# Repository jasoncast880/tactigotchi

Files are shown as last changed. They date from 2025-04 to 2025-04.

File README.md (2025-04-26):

🚀 Project Title

A handheld system based on the Raspberry Pi Pico W
📦 Overview

This project features:

    Custom hardware using RP2040

    Firmware written in C/C++ using GCC & Pico SDK

    Support for SPI LCD Display & SD Card, I2C Buttons, Wi-Fi, BLE, DMA Data Transfer (PIO is WIP)

🔧 Hardware
Microcontroller

    Board: [e.g., Raspberry Pi Pico / STM32F401 / ESP32]

    Processor: [e.g., ARM Cortex-M0+ @ 133MHz]

Schematic & PCB <br>
MCU Schematic:<br>
<br>
PSU:<br>
<br>
LCD/SDC THT Module:<br>
<br>
Speaker && IR Emitter Modules:<br>
<br>

    [Link to schematic or image]

    [Link to PCB files or KiCad/Altium project]

🧠 Firmware
Features

[Feature 1 – e.g., Sensor reading with ADC]

[Feature 2 – e.g., Wi-Fi transmission]

    [Planned Feature – e.g., OTA firmware update]

Toolchain

    Language: C/C++

    Build System: CMake

    RTOS: FreeRTOS

    SDK: Raspberry Pi Pico SDK v1.5.1 (update)

Directory Structure (update...)

project/
├── hardware/         # Schematics, PCB design files
├── pockpet/
└── README.md

🚀 Getting Started
Requirements

    Compiler/toolchain: arm-none-eabi-gcc

    A 'Tactigotchi' official hardware kit!

Building the Firmware

git clone https://github.com/yourusername/project.git
cd project
mkdir build && cd build
cmake ..
make

Flashing to Device

# Example for Raspberry Pi Pico (drag-and-drop)
cp firmware.uf2 /media/PI-PICO/

Or, using OpenOCD / pyOCD:

openocd -f interface/cmsis-dap.cfg -f target/rp2040.cfg

📈 Performance & Testing

    Power consumption: [value]

    Real-time responsiveness: [value / approach used]

    Debugging methods: [e.g., UART, SWD, printf-style logging]

🗂️ Documentation

    [Link to datasheets, application notes, or online documentation]

    [Optional: Link to a GitHub Wiki or Doxygen-generated docs]

🧪 Development Notes

    Known Issues: [List any bugs or limitations]

    Future Work: [Planned improvements or extensions]

    Contributions: [Mention if pull requests/issues are welcome]

📜 License

[MIT / GPL / Apache 2.0 / etc.]
🙌 Acknowledgments

    [Any libraries or codebases used]

    [Contributors, inspirations, mentors]

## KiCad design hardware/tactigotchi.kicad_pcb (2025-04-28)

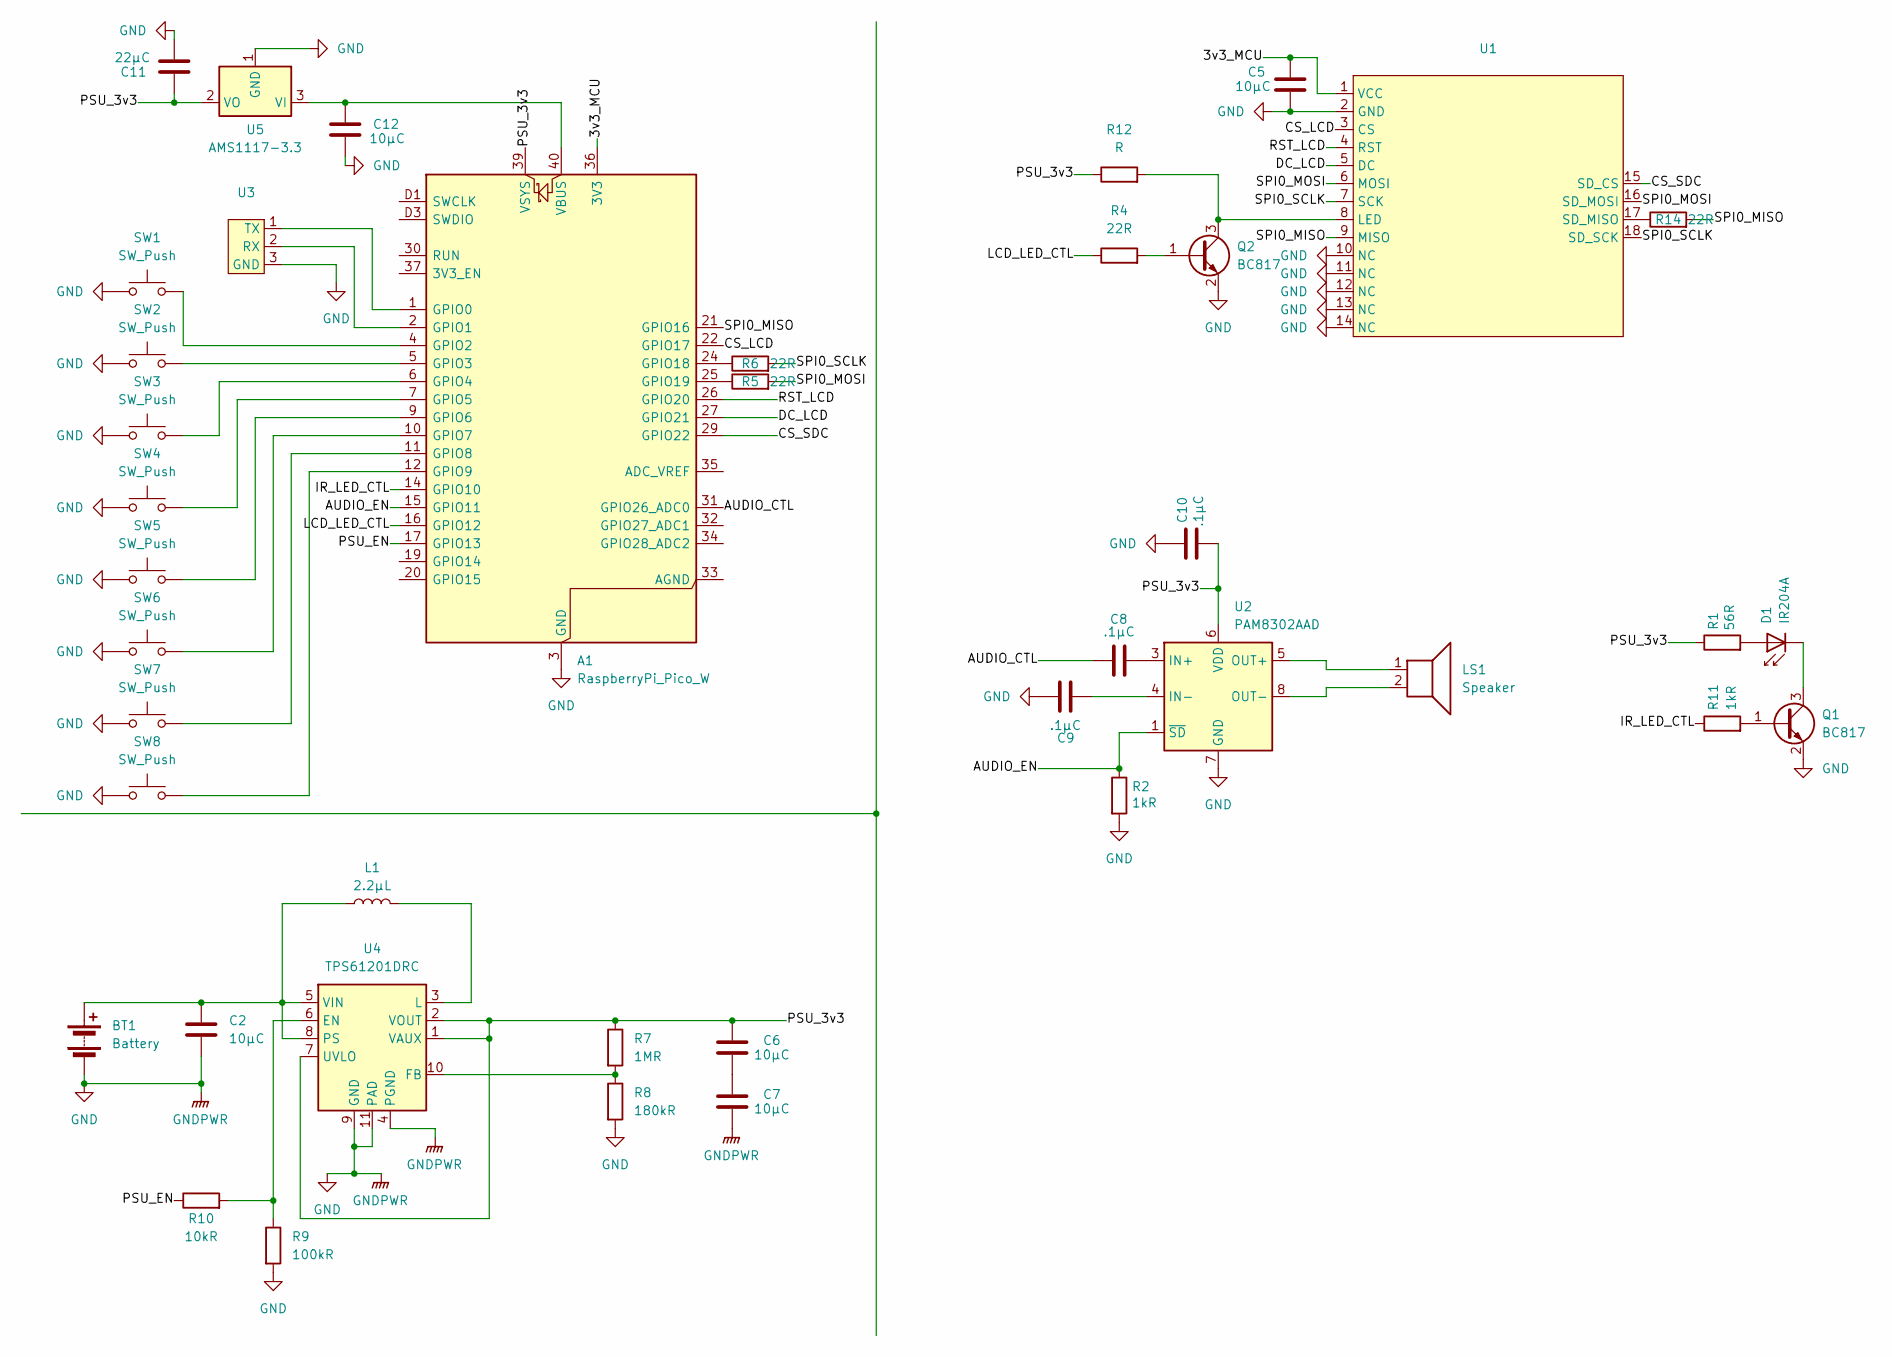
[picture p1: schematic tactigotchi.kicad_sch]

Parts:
A1: RaspberryPi_Pico_W; RaspberryPi_Pico_W_SMD_HandSolder
BT1: Battery; PinHeader_1x02_P1.27mm_Vertical
C2, C5, C6, C7, C12: 10μC; C_1206_3216Metric
C8, C9, C10: .1μC; C_1206_3216Metric
C11: 22μC; C_1206_3216Metric
D1: IR204A; LED_D3.0mm_IRBlack
L1: 2.2μL; L_1206_3216Metric
LS1: Speaker; Buzzer_12x9.5RM7.6
Q1, Q2: BC817; SOT-23
R1: 56R; R_1206_3216Metric
R2, R11: 1kR; R_1206_3216Metric
R4, R5, R6, R14: 22R; R_1206_3216Metric
R7: 1MR; R_1206_3216Metric
R8: 180kR; R_1206_3216Metric
R9: 100kR; R_1206_3216Metric
R10: 10kR; R_1206_3216Metric
R12: R; R_1206_3216Metric
SW1, SW2, SW3, SW4, SW5, SW6, SW7, SW8: SW_Push; SW_SPST_PTS645
U1: ILI9341_Module
U2: PAM8302AAD; SOIC-8-1EP_3.9x4.9mm_P1.27mm_EP2.41x3.3mm
U3: 3x1_PinHeader
U4: TPS61201DRC; Texas_S-PVSON-N10_ThermalVias
U5: AMS1117-3.3; SOT-223-3_TabPin2

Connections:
/3v3_MCU: A1.36 (3V3), C5.1, U1.1 (VCC)
/AUDIO_CTL: A1.31 (GPIO26_ADC0), C8.1
/AUDIO_EN: A1.15 (GPIO11), R2.1, U2.1 (~SD)
/CS_LCD: A1.22 (GPIO17), U1.3 (CS)
/CS_SDC: A1.29 (GPIO22), U1.15 (SD_CS)
/DC_LCD: A1.27 (GPIO21), U1.5 (DC)
/IR_LED_CTL: A1.14 (GPIO10), R11.1
/LCD_LED_CTL: A1.16 (GPIO12), R4.1
/PSU_3v3: A1.39 (VSYS), C6.2, C10.2, C11.1, R1.1, R7.1, R12.1, U2.6 (VDD), U4.1 (VAUX), U4.2 (VOUT), U4.7 (UVLO), U5.2 (VO)
/PSU_EN: A1.17 (GPIO13), R10.1
/RST_LCD: A1.26 (GPIO20), U1.4 (RST)
/SPI0_MISO: A1.21 (GPIO16), R14.2, U1.9 (MISO)
/SPI0_MOSI: R5.2, U1.6 (MOSI), U1.16 (SD_MOSI)
/SPI0_SCLK: R6.2, U1.7 (SCK), U1.18 (SD_SCK)
GND: A1.3 (GND), A1.8 (GND), A1.13 (GND), A1.18 (GND), A1.23 (GND), A1.28 (GND), A1.38 (GND), A1.D2 (GND), BT1.2 (-), C2.2, C5.2, C7.1, C9.2, C10.1, C11.2, C12.2, Q1.2 (E), Q2.2 (E), R2.2, R8.2, R9.2, SW1.1, SW2.1, SW3.1, SW4.1, SW5.1, SW6.1, SW7.1, SW8.1, U1.2 (GND), U1.10 (NC), U1.11 (NC), U1.12 (NC), U1.13 (NC), U1.14 (NC), U2.7 (GND), U3.3 (GND), U4.4 (PGND), U4.9 (GND), U4.11 (PAD), U5.1 (GND)
unnamed: A1.1 (GPIO0), U3.1 (TX)
unnamed: A1.2 (GPIO1), U3.2 (RX)
unnamed: A1.4 (GPIO2), SW1.2
unnamed: A1.5 (GPIO3), SW2.2
unnamed: A1.6 (GPIO4), SW3.2
unnamed: A1.7 (GPIO5), SW4.2
unnamed: A1.9 (GPIO6), SW5.2
unnamed: A1.10 (GPIO7), SW6.2
unnamed: A1.11 (GPIO8), SW7.2
unnamed: A1.12 (GPIO9), SW8.2
unnamed: A1.24 (GPIO18), R6.1
unnamed: A1.25 (GPIO19), R5.1
unnamed: A1.40 (VBUS), C12.1, U5.3 (VI)
unnamed: BT1.1 (+), C2.1, L1.1, U4.5 (VIN), U4.8 (PS)
unnamed: C6.1, C7.2
unnamed: D1.2 (A), R1.2
unnamed: D1.1 (K), Q1.3 (C)
unnamed: Q1.1 (B), R11.2
unnamed: Q2.1 (B), R4.2
unnamed: Q2.3 (C), R12.2, U1.8 (LED)
unnamed: R14.1, U1.17 (SD_MISO)
unnamed: C8.2, U2.3 (IN+)
unnamed: C9.1, U2.4 (IN-)
unnamed: LS1.1, U2.5 (OUT+)
unnamed: LS1.2, U2.8 (OUT-)
unnamed: R9.1, R10.2, U4.6 (EN)
unnamed: R7.2, R8.1, U4.10 (FB)
unnamed: L1.2, U4.3 (L)

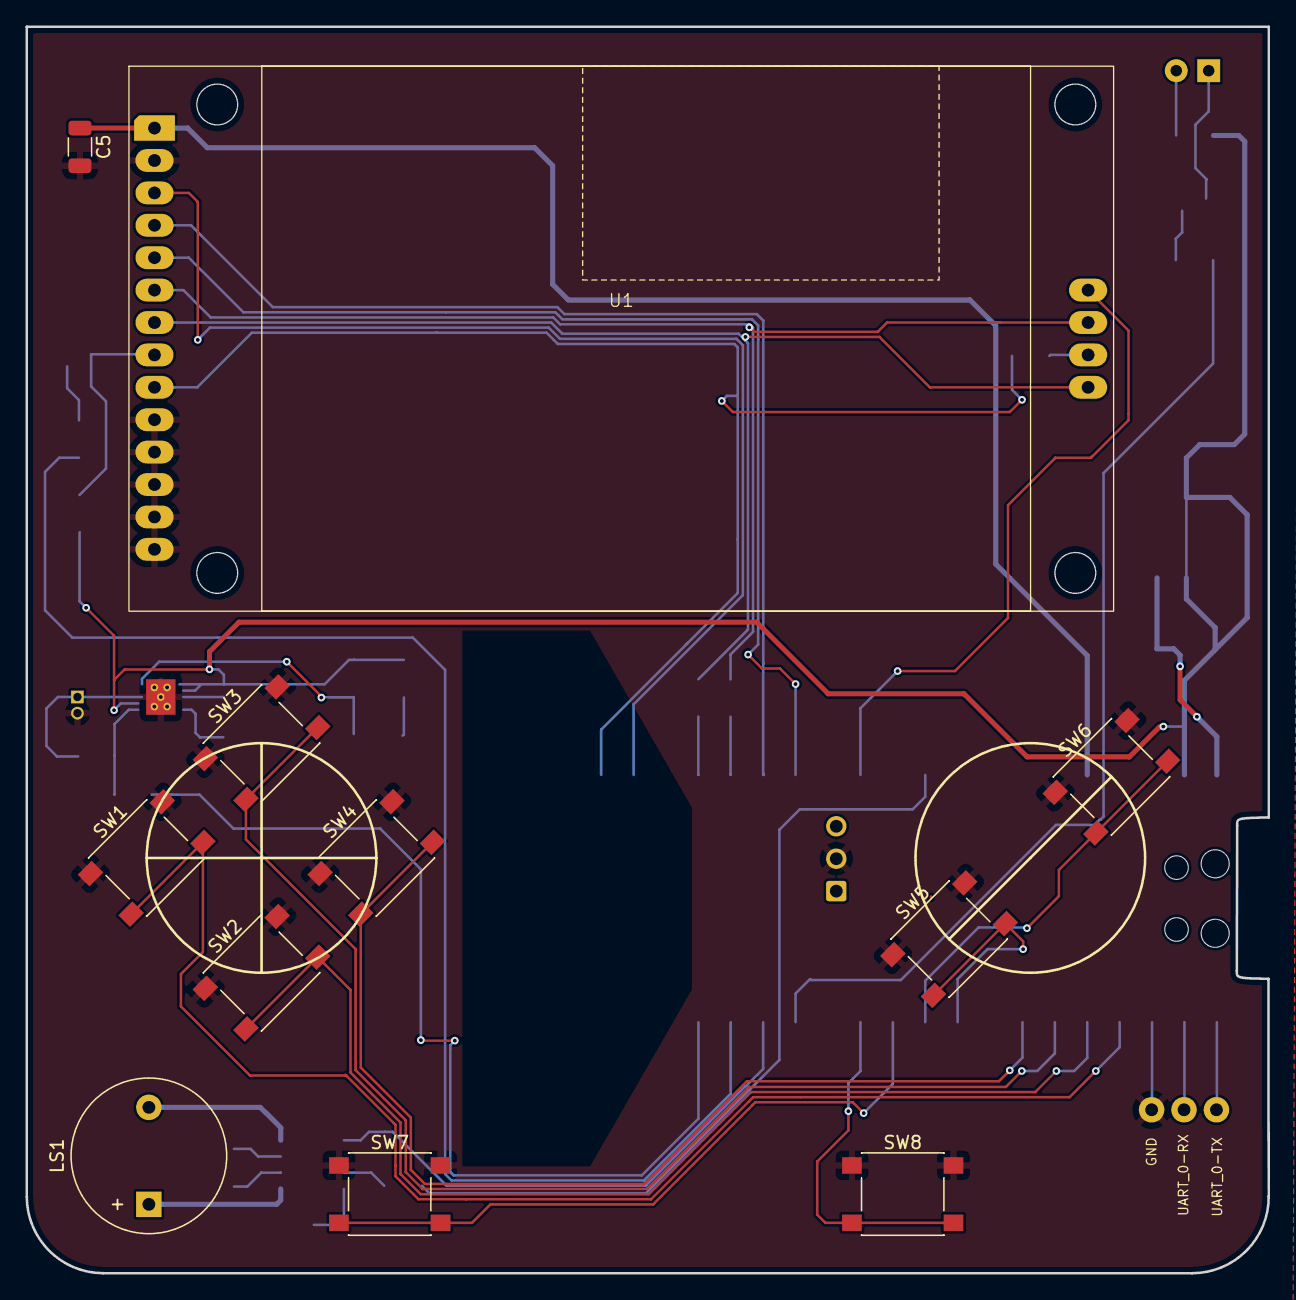
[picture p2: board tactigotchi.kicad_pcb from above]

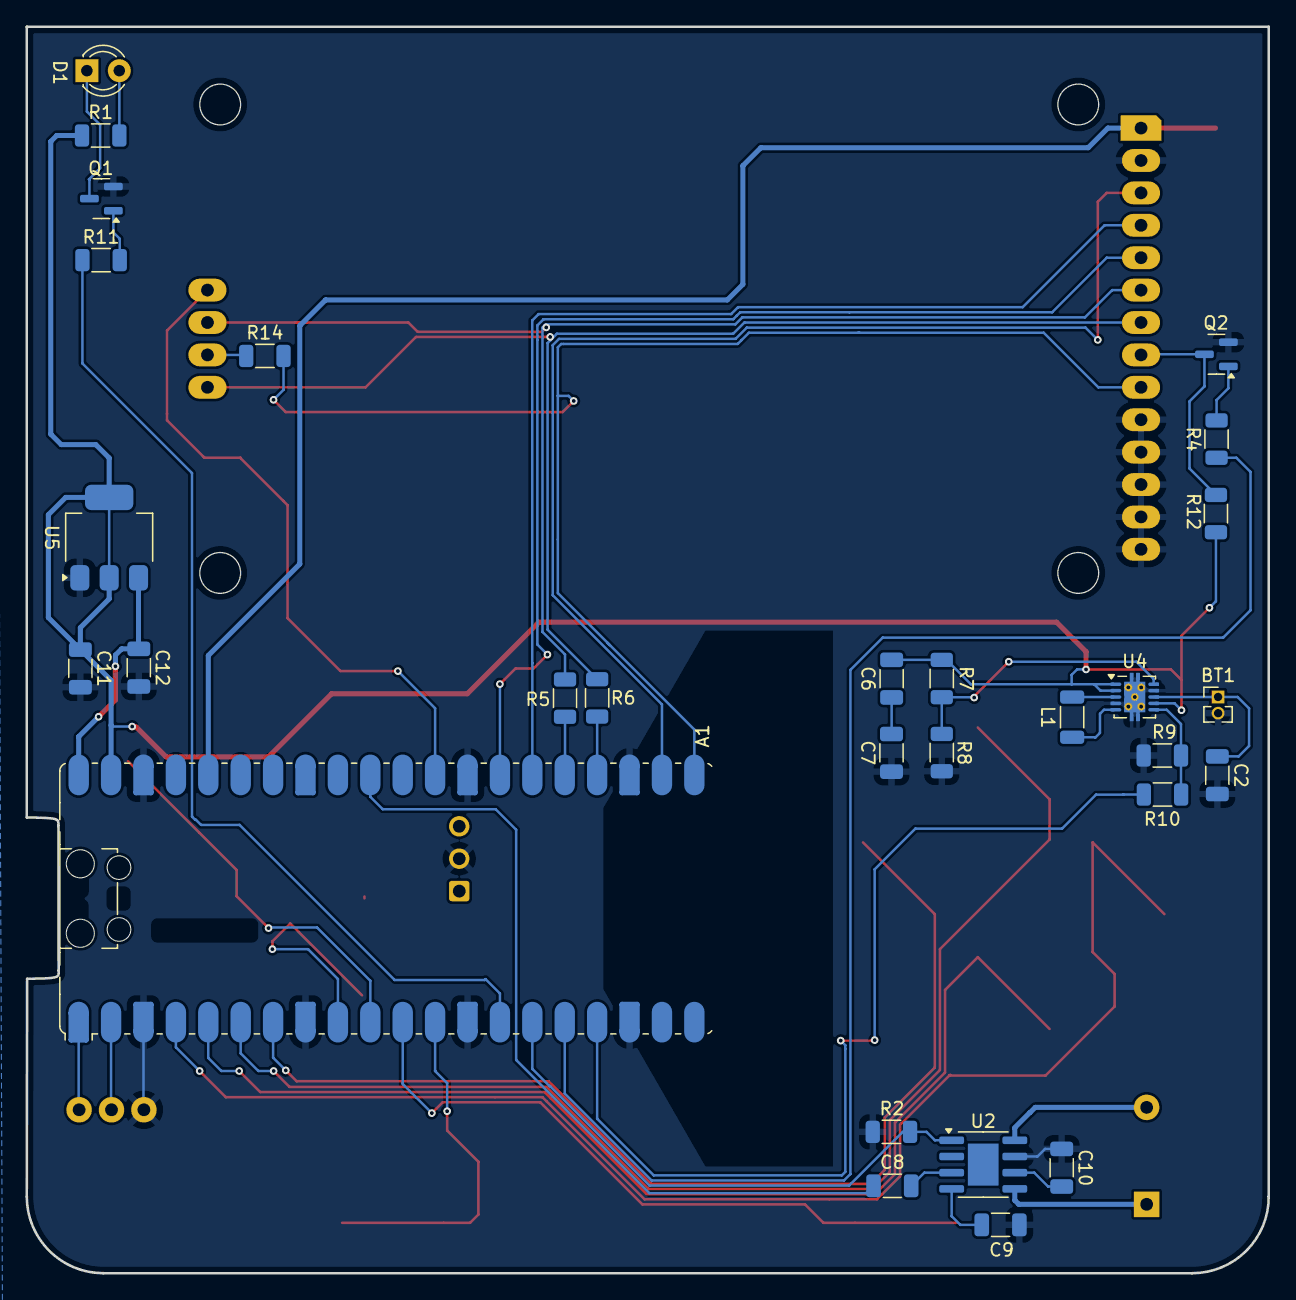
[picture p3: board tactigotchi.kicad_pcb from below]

Board: 2 copper layers, 97.4 x 97.7 mm, 41 parts (29 on the bottom side), 43 nets.

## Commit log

2025-04-21 Add files via upload
    handheld_pico project files.
    [ampalaya.kicad_sch, handheld_pico.kicad_pcb, handheld_pico.kicad_sch]
2025-04-24 HW v.0.1: no layout, all tht components
    [ampalaya.kicad_sch, handheld_pico.kicad_pcb, handheld_pico.kicad_sch]
2025-04-26 Add files via upload
    smd schematic drop-in replacements, changes to psu module
    [tactigotchi.kicad_sch]
2025-04-26 beginnings of pcb layout
    [tactigotchi.kicad_pcb, tactigotchi.kicad_sch]
